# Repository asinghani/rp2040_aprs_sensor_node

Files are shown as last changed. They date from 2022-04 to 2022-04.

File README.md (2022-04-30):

# RP2040 APRS Sensor Node

Cheap, low-power embedded sensor-node powered by an RP2040 microcontroller that communicates over the APRS (Automatic Packet Reporting System) network using the VHF Amateur Radio band.

### Features

- RP2040 microcontroller + flash memory
    - Ability to run MicroPython
- USB-C for power and programming
- JST connector for connecting to LiPo batteries
- 3V3 regulator to power microcontroller (and optionally radio)
- DRA818 VHF 1W/0.5W transceiver
    - Passive bandpass filter converts PWM output to sine-wave for transmission
    - SMA antenna connector (can use a rubber-ducky style HT antenna or an SMA cable to connect to a later antenna)
- Reset & reflash buttons, power & user LEDs
- Power-source jumpers
    - 3V3 regulator can be powered by USB or JST
    - Radio transceiver can be powered directly by JST or thru 3V3 regulator

### Photos

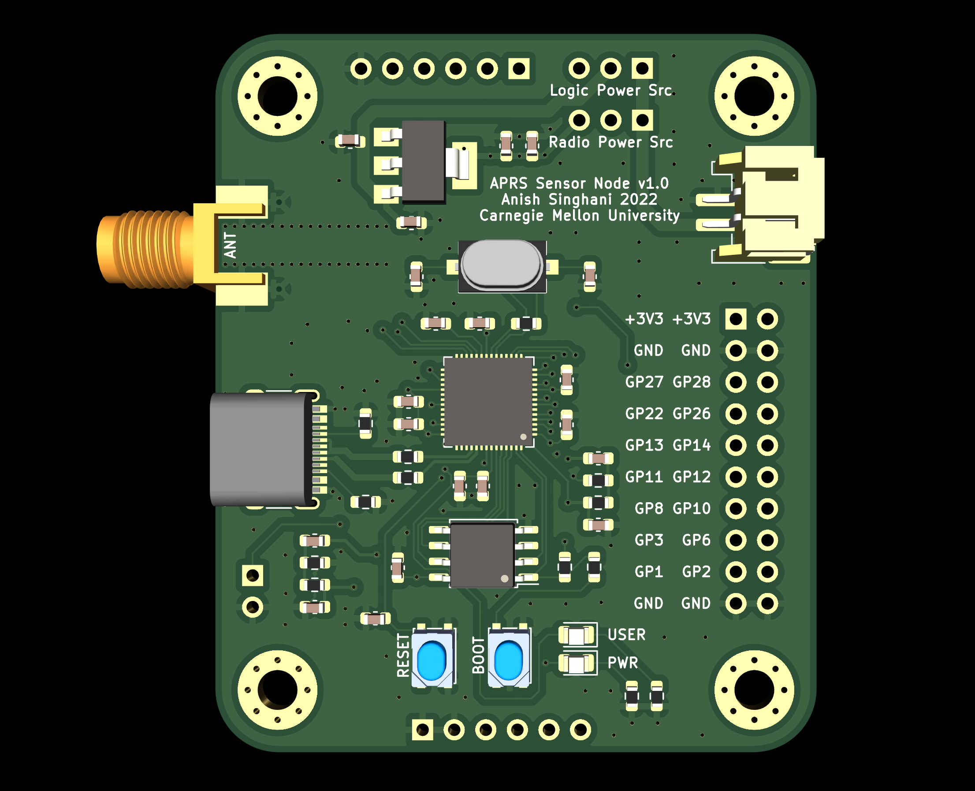
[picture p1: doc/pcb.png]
PCB rendering


Device image

### Example Code

The directory `firmware` includes example code which reads from a [TMP102 temperature sensor](https://www.sparkfun.com/products/13314) and transmits over the APRS network. The pinout for the sensor is defined in `firmware/src/tmp102.c`.

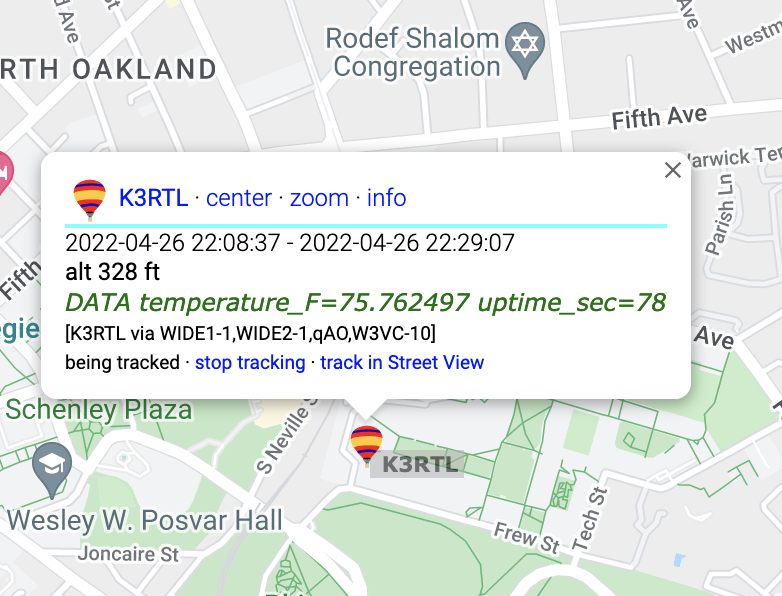
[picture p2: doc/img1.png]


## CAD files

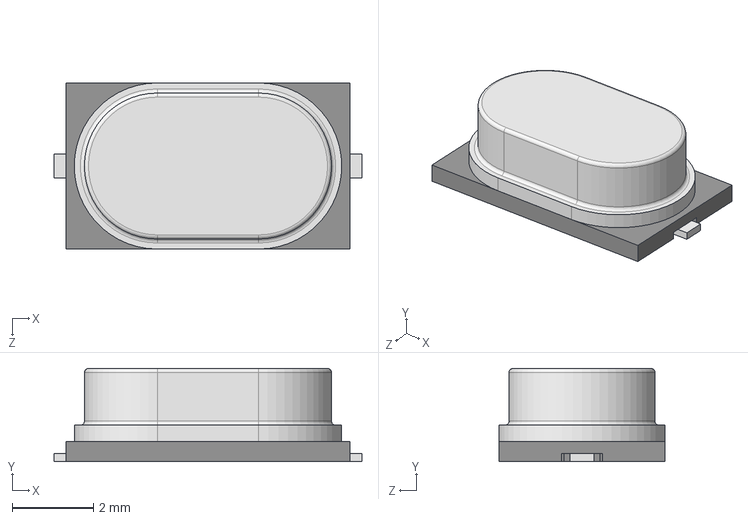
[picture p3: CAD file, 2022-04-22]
node_pcb_v1/parts/ECS-120-20-3X-TR/ECS-120-20-3X-TR.step
7.60 x 2.30 x 4.10 mm

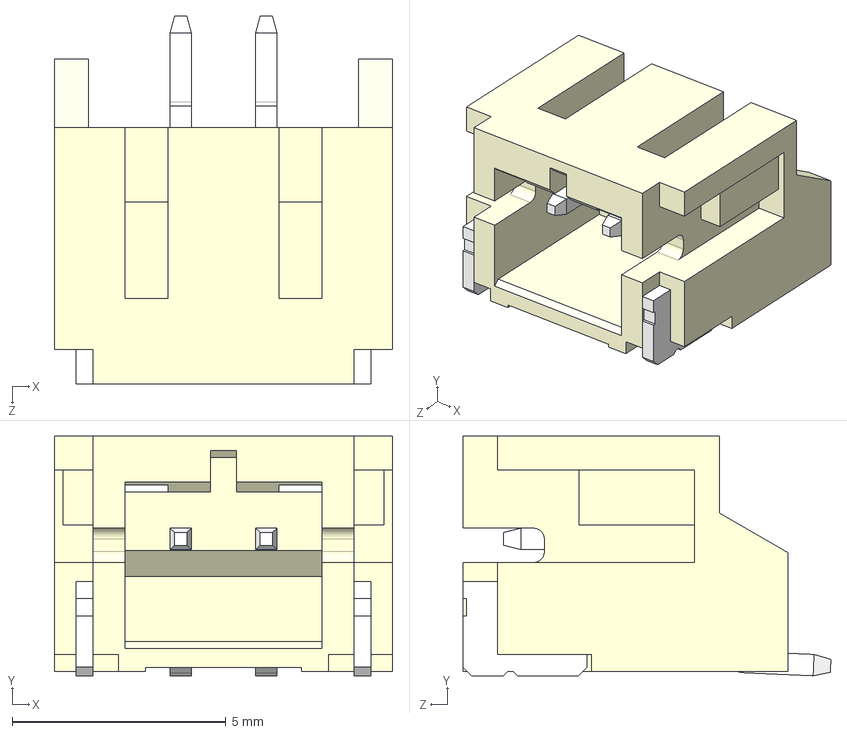
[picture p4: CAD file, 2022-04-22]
node_pcb_v1/parts/JST-S2B-PH-SM4-TB/JST-S2B-PH-SM4-TB.STEP
7.90 x 5.60 x 8.60 mm

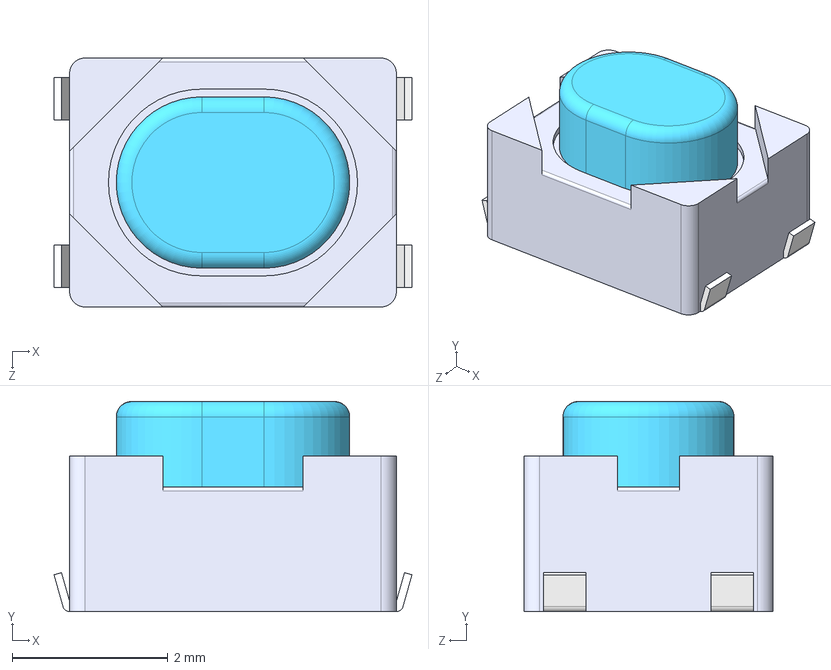
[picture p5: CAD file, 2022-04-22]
node_pcb_v1/parts/PTS810/PTS810.STEP
4.60 x 2.70 x 3.20 mm

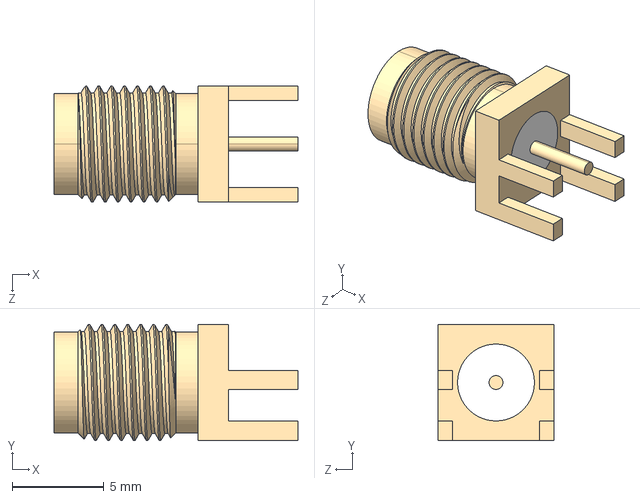
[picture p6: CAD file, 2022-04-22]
node_pcb_v1/parts/SMA-EDGE-CONN/SMA-EDGE-CONN.STEP
13.3 x 6.35 x 6.35 mm

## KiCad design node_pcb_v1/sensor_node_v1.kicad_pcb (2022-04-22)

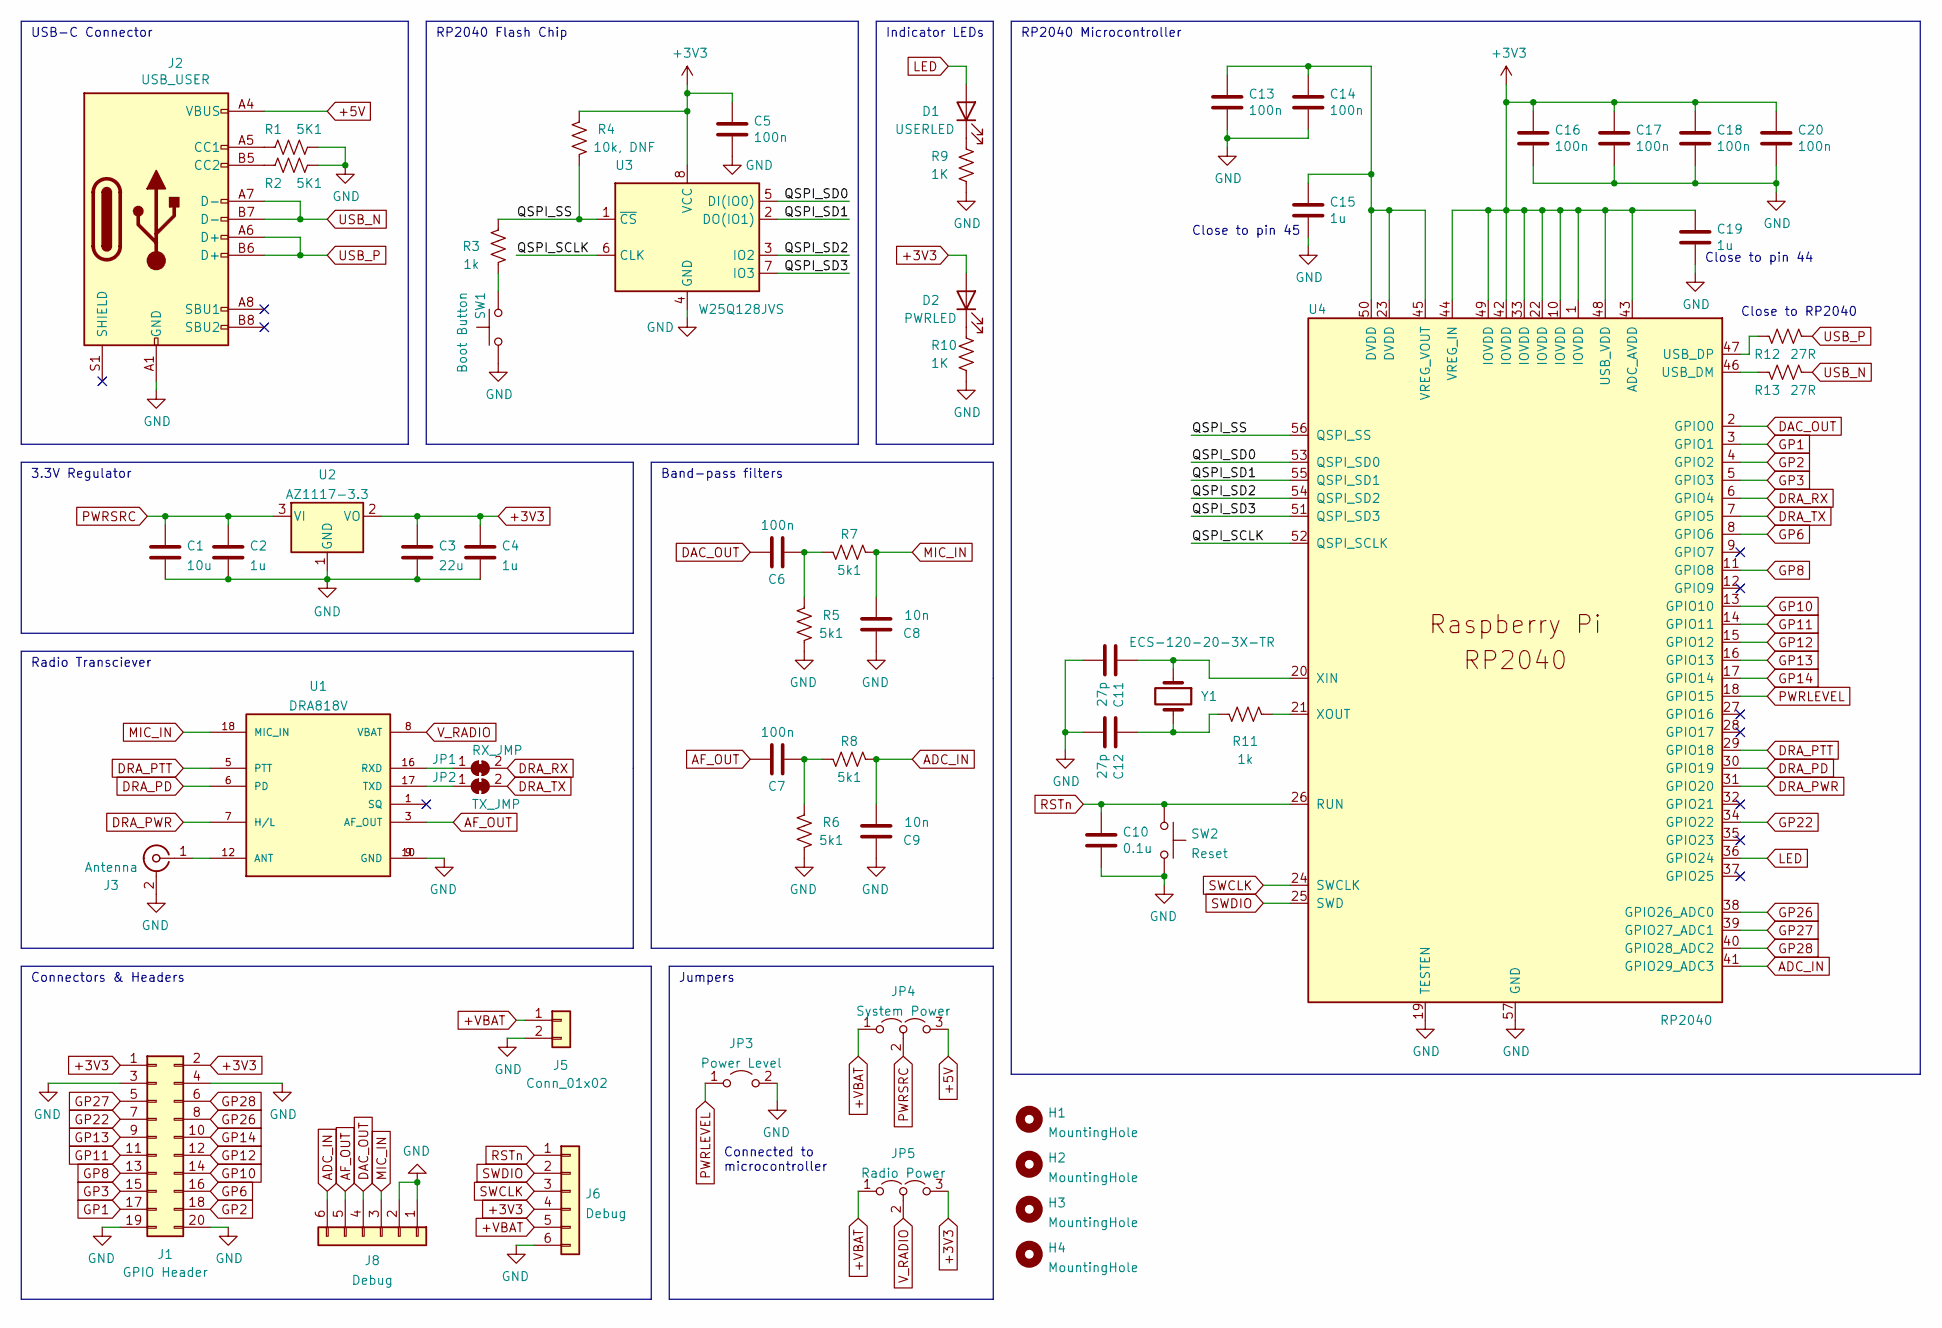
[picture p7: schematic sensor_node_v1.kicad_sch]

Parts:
C1: 10u; C_0603_1608Metric
C2, C4, C15, C19: 1u; C_0603_1608Metric
C3: 22u; C_0603_1608Metric
C5, C6, C7, C13, C14, C16, C17, C18, C20: 100n; C_0603_1608Metric
C8, C9: 10n; C_0603_1608Metric
C10: 0.1u; C_0603_1608Metric
C11, C12: 27p; C_0603_1608Metric
D1: USERLED; LED_0805_2012Metric
D2: PWRLED; LED_0805_2012Metric
H1, H2, H3, H4: MountingHole; MountingHole_3.2mm_M3_Pad_Via
J1: GPIO Header; PinHeader_2x10_P2.54mm_Vertical
J2: USB_USER; USB_C_HRO-31-M-12_nofront
J3: Antenna; SMA_Molex_73251-2120_EdgeMount_Horizontal
J5: Conn_01x02; JST_PH_S2B-PH-SM4-TB_1x02-1MP_P2.00mm_Horizontal
J6, J8: Debug; PinHeader_1x06_P2.54mm_Vertical
JP1: RX_JMP; SolderJumper-2_P1.3mm_Bridged_Pad1.0x1.5mm
JP2: TX_JMP; SolderJumper-2_P1.3mm_Bridged_Pad1.0x1.5mm
JP3: Power Level; PinHeader_1x02_P2.54mm_Vertical
JP4: System Power; PinHeader_1x03_P2.54mm_Vertical
JP5: Radio Power; PinHeader_1x03_P2.54mm_Vertical
R1, R2: 5K1; R_0603_1608Metric
R3, R11: 1k; R_0603_1608Metric
R4: 10k, DNF; R_0603_1608Metric
R5, R6, R7, R8: 5k1; R_0603_1608Metric
R9, R10: 1K; R_0603_1608Metric
R12, R13: 27R; R_0603_1608Metric
SW1: Boot Button; SW_SPST_PTS810
SW2: Reset; SW_SPST_PTS810
U1: DRA818V; DORJI_DRA818V; PART_REV 1.23
U2: AZ1117-3.3; SOT-223-3_TabPin2
U3: W25Q128JVS; SOIC-8_5.23x5.23mm_P1.27mm
U4: RP2040; RP2040-QFN-56
Y1: ECS-120-20-3X-TR; XTAL_ECS-120-20-3X-TR

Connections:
+3V3: C3.1, C4.1, C5.1, C16.1, C17.1, C18.1, C19.1, C20.1, D2.2 (A), J1.1, J1.2, J6.4, JP5.3 (B), R4.1, U2.2 (VO), U3.8 (VCC), U4.1 (IOVDD), U4.10 (IOVDD), U4.22 (IOVDD), U4.33 (IOVDD), U4.42 (IOVDD), U4.43 (ADC_AVDD), U4.44 (VREG_IN), U4.48 (USB_VDD), U4.49 (IOVDD)
+5V: J2.A4 (VBUS), J2.A9 (VBUS), J2.B4 (VBUS), J2.B9 (VBUS), JP4.3 (B)
+VBAT: J5.1, J6.5, JP4.1 (A), JP5.1 (A)
/QSPI_SCLK: U3.6 (CLK), U4.52 (QSPI_SCLK)
/QSPI_SD0: U3.5 (DI(IO0)), U4.53 (QSPI_SD0)
/QSPI_SD1: U3.2 (DO(IO1)), U4.55 (QSPI_SD1)
/QSPI_SD2: U3.3 (IO2), U4.54 (QSPI_SD2)
/QSPI_SD3: U3.7 (IO3), U4.51 (QSPI_SD3)
/QSPI_SS: R3.2, R4.2, U3.1 (~CS), U4.56 (QSPI_SS)
ADC_IN: C9.2, J8.6, R8.2, U4.41 (GPIO29_ADC3)
AF_OUT: C7.1, J8.5, U1.3 (AF_OUT)
DAC_OUT: C6.1, J8.4, U4.2 (GPIO0)
DRA_PD: U1.6 (PD), U4.30 (GPIO19)
DRA_PTT: U1.5 (PTT), U4.29 (GPIO18)
DRA_PWR: U1.7 (H/L), U4.31 (GPIO20)
DRA_RX: JP1.2 (B), U4.6 (GPIO4)
DRA_TX: JP2.2 (B), U4.7 (GPIO5)
GND: C1.2, C2.2, C3.2, C4.2, C5.2, C8.1, C9.1, C10.2, C11.2, C12.2, C13.2, C14.2, C15.2, C16.2, C17.2, C18.2, C19.2, C20.2, J1.3, J1.4, J1.19, J1.20, J2.A1 (GND), J2.A12 (GND), J2.B1 (GND), J2.B12 (GND), J3.2 (Ext), J5.2, J6.6, J8.1, J8.2, JP3.2 (B), R1.2, R2.2, R5.2, R6.2, R9.2, R10.2, SW1.1, SW2.2, U1.9 (GND), U1.10 (GND), U2.1 (GND), U3.4 (GND), U4.19 (TESTEN), U4.57 (GND)
GP1: J1.17, U4.3 (GPIO1)
GP2: J1.18, U4.4 (GPIO2)
GP3: J1.15, U4.5 (GPIO3)
GP6: J1.16, U4.8 (GPIO6)
GP8: J1.13, U4.11 (GPIO8)
GP10: J1.14, U4.13 (GPIO10)
GP11: J1.11, U4.14 (GPIO11)
GP12: J1.12, U4.15 (GPIO12)
GP13: J1.9, U4.16 (GPIO13)
GP14: J1.10, U4.17 (GPIO14)
GP22: J1.7, U4.34 (GPIO22)
GP26: J1.8, U4.38 (GPIO26_ADC0)
GP27: J1.5, U4.39 (GPIO27_ADC1)
GP28: J1.6, U4.40 (GPIO28_ADC2)
LED: D1.2 (A), U4.36 (GPIO24)
MIC_IN: C8.2, J8.3, R7.2, U1.18 (MIC_IN)
unnamed: C6.2, R5.1, R7.1
unnamed: C7.2, R6.1, R8.1
unnamed: C11.1, U4.20 (XIN), Y1.1
unnamed: C12.1, R11.2, Y1.2
unnamed: C13.1, C14.1, C15.1, U4.23 (DVDD), U4.45 (VREG_VOUT), U4.50 (DVDD)
unnamed: D1.1 (K), R9.1
unnamed: D2.1 (K), R10.1
unnamed: J2.A5 (CC1), R1.1
unnamed: J2.B5 (CC2), R2.1
unnamed: J3.1 (In), U1.12 (ANT)
unnamed: JP1.1 (A), U1.16 (RXD)
unnamed: JP2.1 (A), U1.17 (TXD)
unnamed: R3.1, SW1.2
unnamed: R11.1, U4.21 (XOUT)
unnamed: R12.2, U4.47 (USB_DP)
unnamed: R13.2, U4.46 (USB_DM)
PWRLEVEL: JP3.1 (A), U4.18 (GPIO15)
PWRSRC: C1.1, C2.1, JP4.2 (C), U2.3 (VI)
RSTn: C10.1, J6.1, SW2.1, U4.26 (RUN)
SWCLK: J6.3, U4.24 (SWCLK)
SWDIO: J6.2, U4.25 (SWD)
USB_N: J2.A7 (D-), J2.B7 (D-), R13.1
USB_P: J2.A6 (D+), J2.B6 (D+), R12.1
V_RADIO: JP5.2 (C), U1.8 (VBAT)

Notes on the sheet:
RP2040 Microcontroller
USB-C Connector
3.3V Regulator
Radio Transciever
Jumpers
RP2040 Flash Chip
Connected to microcontroller
Connectors & Headers
Band-pass filters
Indicator LEDs
Close to pin 44
Close to RP2040
Close to pin 45

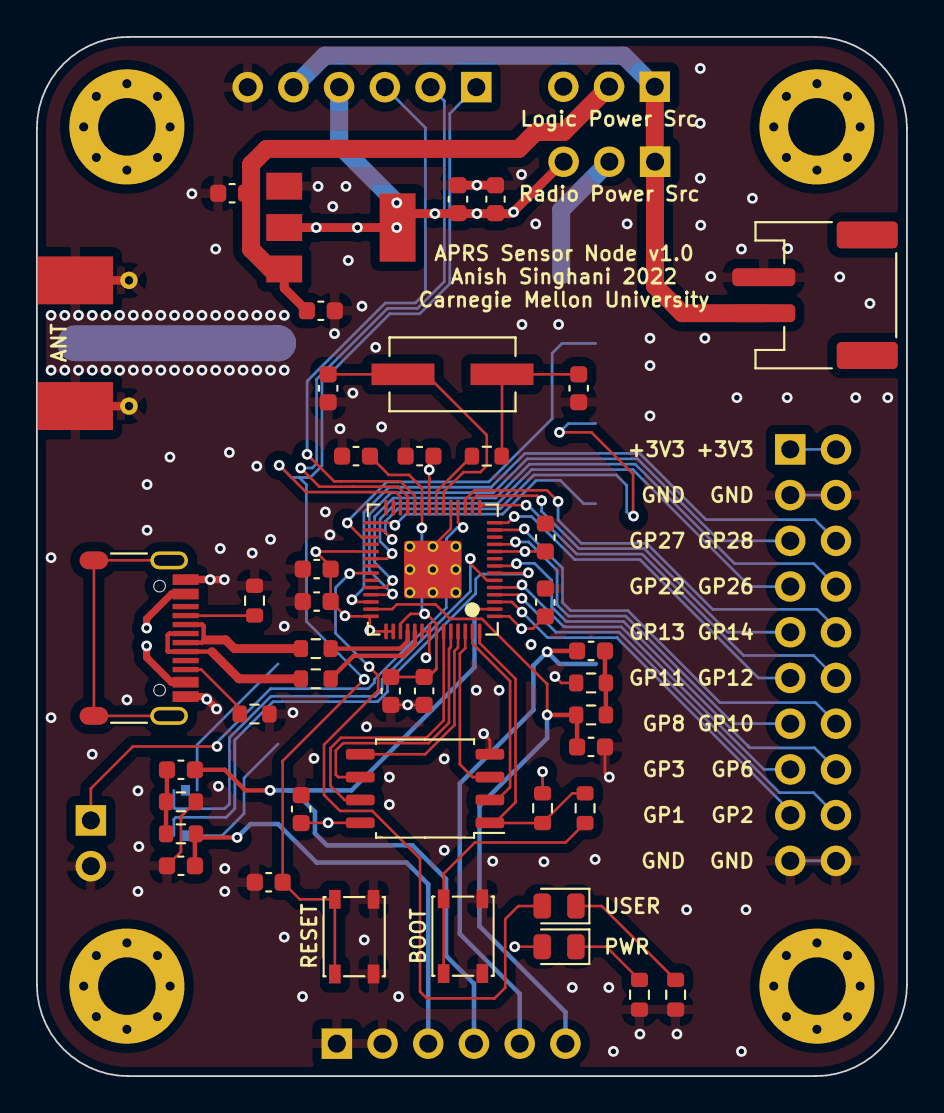
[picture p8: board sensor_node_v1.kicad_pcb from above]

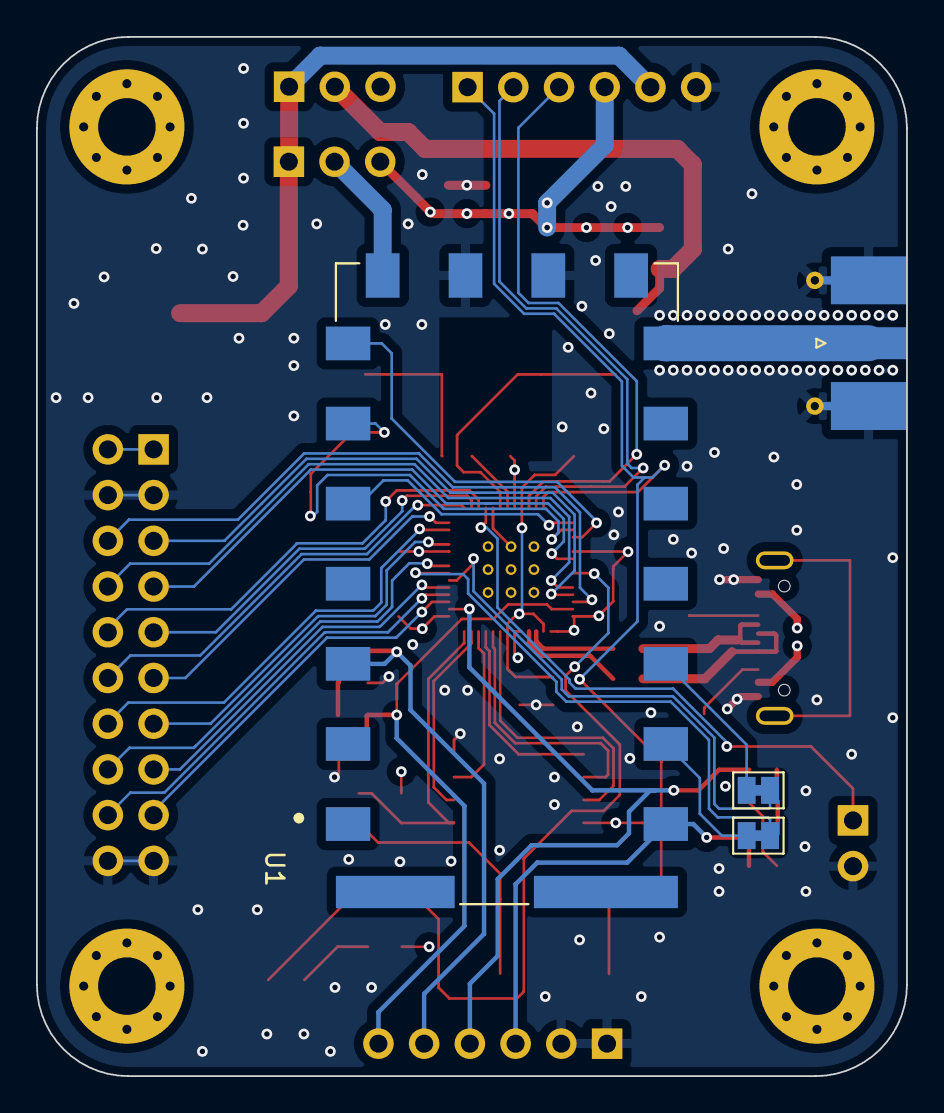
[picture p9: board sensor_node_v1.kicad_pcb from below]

Board: 4 copper layers, 48.3 x 57.7 mm, 57 parts (4 on the bottom side), 58 nets.

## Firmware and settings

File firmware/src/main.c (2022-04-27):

#include <aprs_pico.h>
#include <pico/stdlib.h>
#include <stdio.h>
#include "dra818.h"
#include "tmp102.h"

#define LED 24

// This should ideally be once every few minutes at most
// in order to avoid congesting / abusing the APRS network
#define TX_INTERVAL_MS 60000
#define TX_AMPL 200 // Out of 256

// NOTE: Insert user callsign here
#define CALLSIGN "-----"

// NOTE: Insert destination callsign here
#define DST_CALLSIGN "-----"

// For a sensor-node, we expect the location of the node to
// be fixed and as-such we avoid including a GPS module for
// cost reasons, so the coordinates are hard-coded. For a
// mobile platform, these coordinates would be obtained with GPS
#define LAT 40.4422
#define LNG -79.9467
#define ALT 100.0

int main() {
    sleep_ms(2000);

    stdio_init_all();
    tmp102_init();
    sleep_ms(2000);
    dra818_init_aprs();
    dra818_set_lowpower(true);
    sleep_ms(2000);

    void* aprs = aprs_pico_init();

    char msg[128];
    while (true) {
        // Read and transmit the temperature and device uptime
        float temp = tmp102_read_temperature();
        uint64_t uptime = to_us_since_boot(get_absolute_time()) / 1000 / 1000;
        sprintf(msg, "DATA temperature_F=%f uptime_sec=%lu", temp, uptime);

        // Transmit the data
        dra818_key(true);
        aprs_pico_sendAPRS(aprs, CALLSIGN, DST_CALLSIGN,
            "WIDE1-1", "WIDE2-1",
            msg, LAT, LNG, ALT, TX_AMPL);
        dra818_key(false);

        sleep_ms(TX_INTERVAL_MS);
    }

    return 0;
}

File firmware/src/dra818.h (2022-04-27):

#include <stdbool.h>

#define DRA_RX 4
#define DRA_TX 5

#define DRA_PTT 18
#define DRA_PD 19
#define DRA_PWR 20

void dra818_init_aprs();
void dra818_set_lowpower(bool low_power);

void dra818_key(bool transmit);
